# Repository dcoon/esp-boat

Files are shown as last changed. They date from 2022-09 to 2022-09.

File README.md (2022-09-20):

# ESP32 Multitool

ESP32 Multitool is an I/O board for ESP32 microcontroller based projects.  It is designed for IoT projects on a boat but can be used in automotive, RV, and home environments.  It is designed to be inexpensive, robust, energy efficient, and easy to use.  It supports firmware from multiple open source projects including ESPHome, ESPSense, and Platformio.

![[esp32-multitool.png]]

## Features

- 4x Analog Inputs
	- +0-30VDC
	- Measure voltage or resistance
- 4x Digital Inputs
- 4x PWM/Switch Outputs
	- Configurable voltage from VIN, +5V, and External
	- 1A current per channel
- CAN/N2K 
- 1-Wire
- I2C
	- Qwiic and Adafruit compatible I2C connector
- Power
	- +5 - 30VDC Input
	- OVP, RV, and ESD Protection
- Software Compatibility
	- ESPHome
	- ESPSense
	- Platformio

## Examples

TBD

### Tank Level Monitor
### Engine Monitor
### Fan Controller
### LED Dimmer

### More
- Refridgerator Controller
- Barometer & Lightning Detector

## Acknowledgements

### Sailorhat

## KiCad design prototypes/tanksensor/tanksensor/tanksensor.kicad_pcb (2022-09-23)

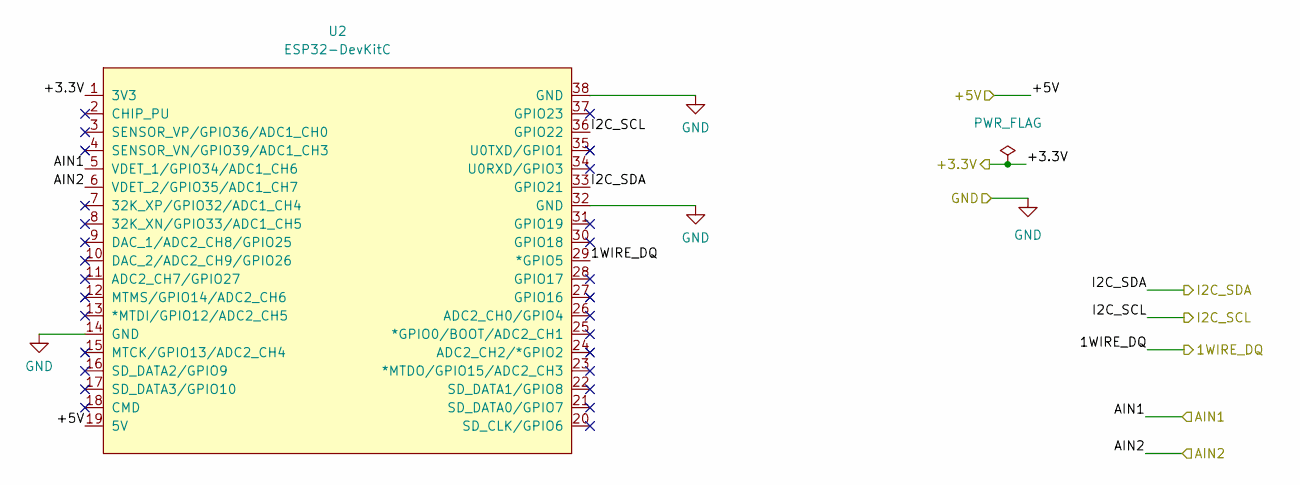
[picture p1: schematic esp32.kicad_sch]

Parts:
U2: ESP32-DevKitC; LCSC n/a

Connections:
+3.3V: U2.1 (3V3); also elsewhere on the board
/1WIRE_DQ: U2.29 (*GPIO5); also elsewhere on the board
/+5V: U2.19 (5V); also elsewhere on the board
/AIN1: U2.5 (VDET_1/GPIO34/ADC1_CH6); also elsewhere on the board
/AIN2: U2.6 (VDET_2/GPIO35/ADC1_CH7); also elsewhere on the board
/I2C_SCL: U2.36 (GPIO22); also elsewhere on the board
/I2C_SDA: U2.33 (GPIO21); also elsewhere on the board
GND: U2.14 (GND), U2.32 (GND), U2.38 (GND); also elsewhere on the board

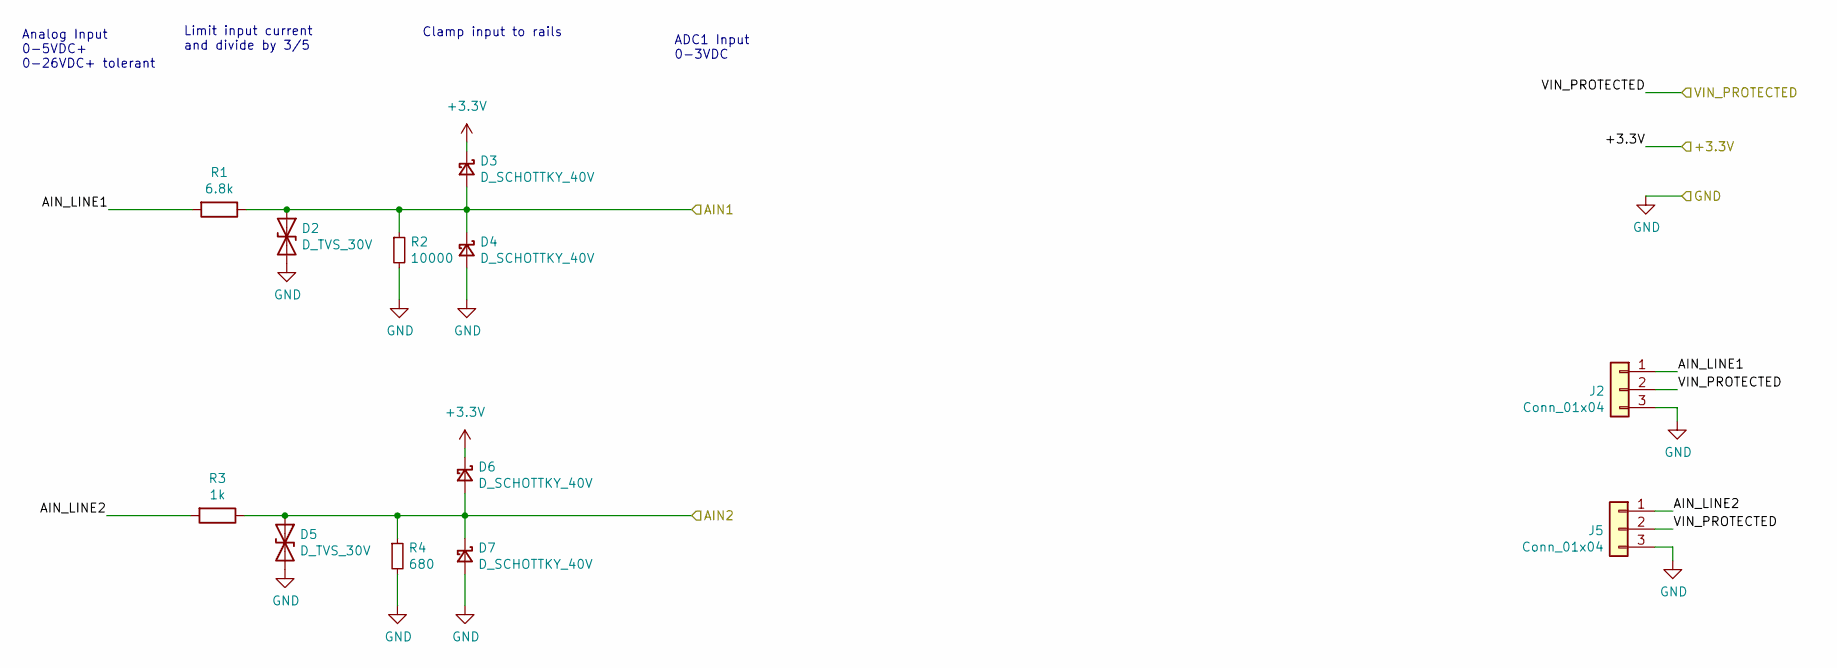
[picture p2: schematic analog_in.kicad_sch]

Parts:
D2, D5: D_TVS_30V; D_SOD-123F; Part SMFJ30CA; LCSC C511921
D3, D4, D6, D7: D_SCHOTTKY_40V; D_SMA; Part B5819W SL; LCSC C8598
J2, J5: Conn_01x04; Molex_KK-254_AE-6410-03A_1x03_P2.54mm_Vertical; Part C145961; LCSC C145961
R1: 6.8k; R_0805_2012Metric; Part 0603WAF1003T5E; LCSC C25803
R2: 10000; R_0805_2012Metric; Part 0603WAF1004T5E; LCSC C22935
R3: 1k; R_0805_2012Metric; Part 0603WAF1003T5E; LCSC C25803
R4: 680; R_0805_2012Metric; Part 0603WAF1004T5E; LCSC C22935

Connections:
+3.3V: D3.1 (K), D6.1 (K); also elsewhere on the board
/AIN1: D2.1 (A1), D3.2 (A), D4.1 (K), R1.1, R2.1; also elsewhere on the board
/AIN2: D5.1 (A1), D6.2 (A), D7.1 (K), R3.1, R4.1; also elsewhere on the board
/VIN_PROTECTED: J2.2, J5.2; also elsewhere on the board
/analog_in/AIN_LINE1: J2.1, R1.2
/analog_in/AIN_LINE2: J5.1, R3.2
GND: D2.2 (A2), D4.2 (A), D5.2 (A2), D7.2 (A), J2.3, J5.3, R2.2, R4.2; also elsewhere on the board

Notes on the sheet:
ADC1 Input 0-3VDC
Limit input current and divide by 3/5
Analog Input 0-5VDC+ 0-26VDC+ tolerant
Clamp input to rails

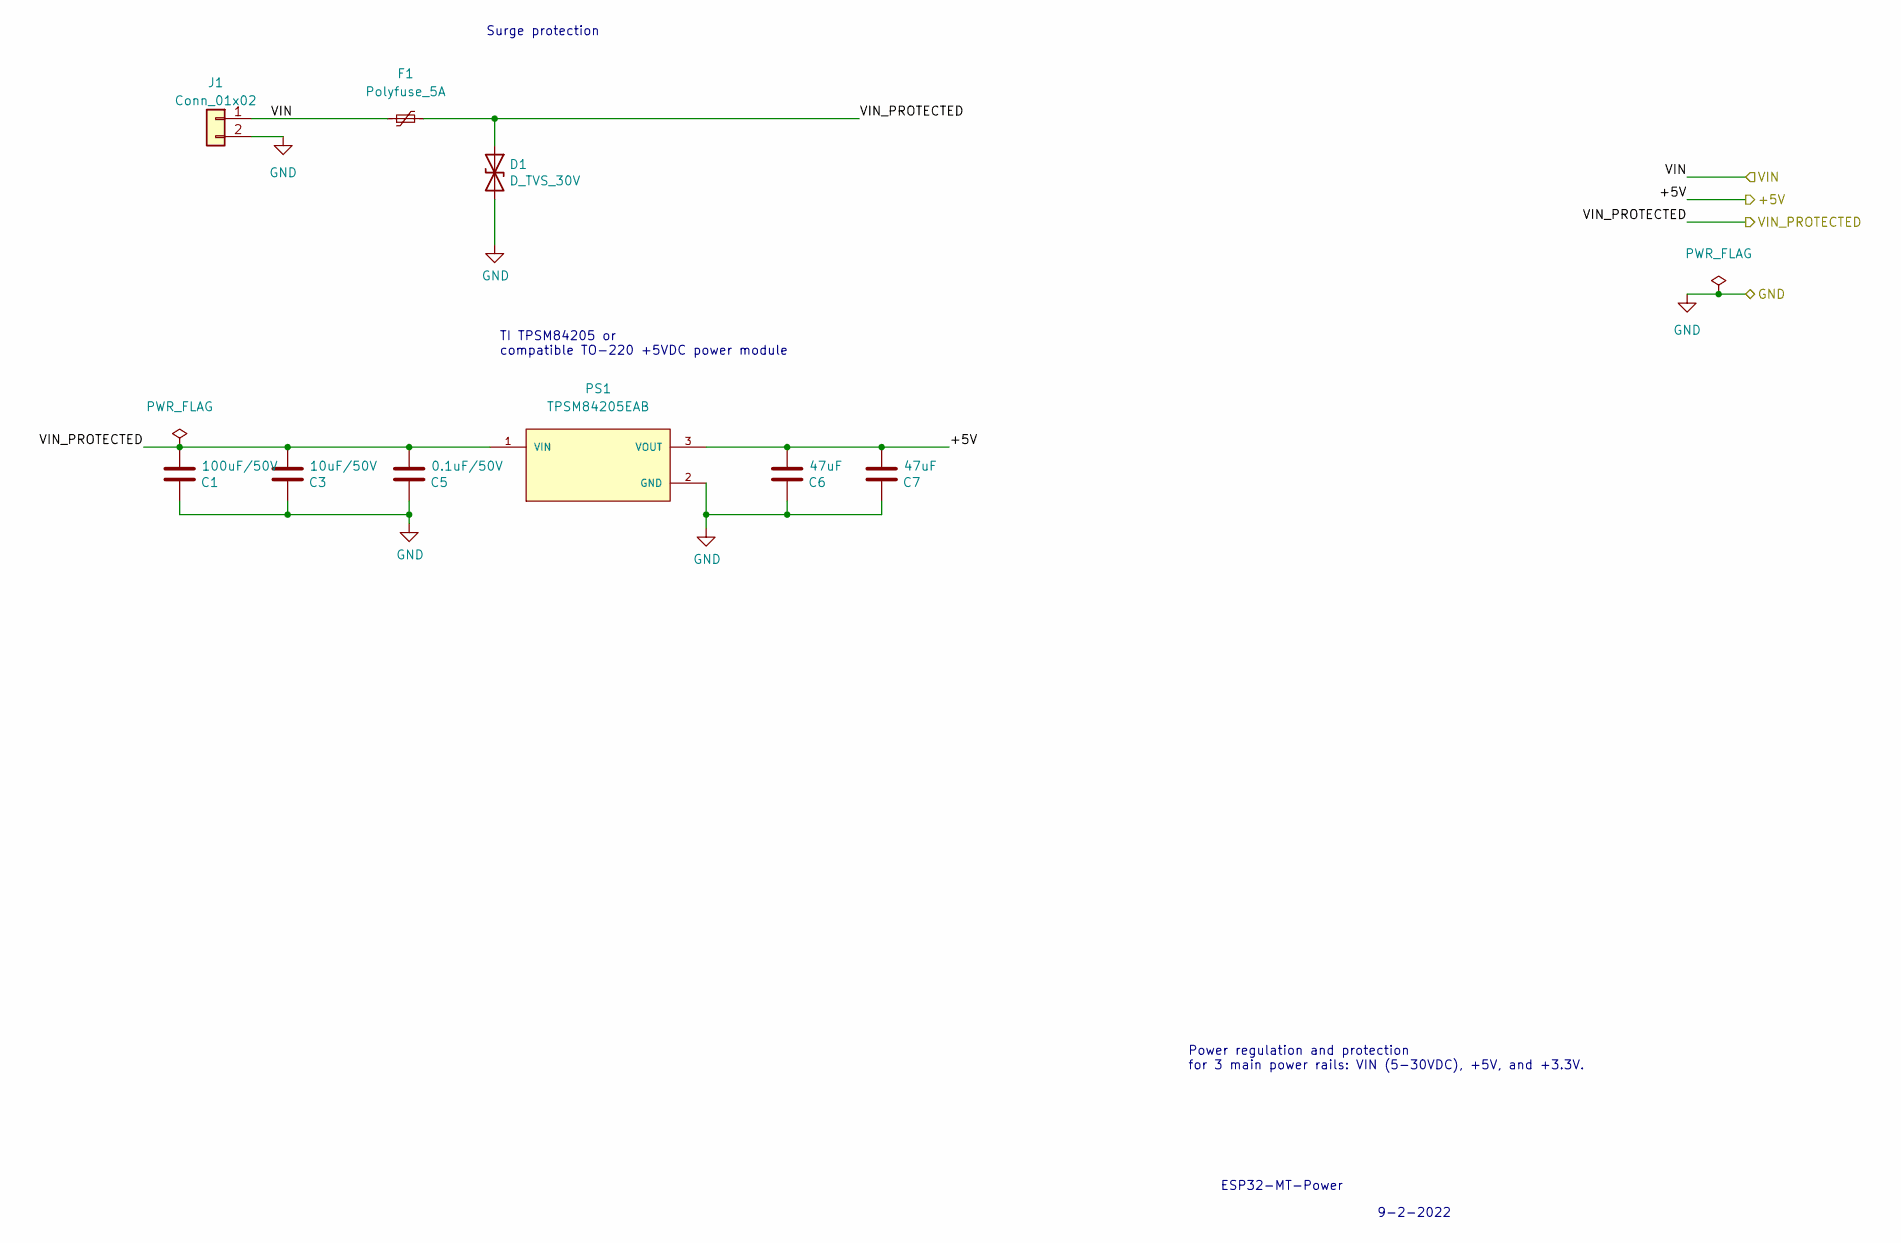
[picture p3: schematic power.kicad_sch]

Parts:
C1: 100uF/50V; C_0805_2012Metric; Part GRM21BR61H106KE43L; LCSC C440198
C3: 10uF/50V; C_0805_2012Metric; Part GRM21BR61H106KE43L; LCSC C440198
C5: 0.1uF/50V; C_0805_2012Metric; Part GRM21BR61H106KE43L; LCSC C440198
C6, C7: 47uF; C_0805_2012Metric; Part GRM21BR61H106KE43L; LCSC C440198
D1: D_TVS_30V; D_SOD-123F; Part SMFJ30CA; LCSC C511921
F1: Polyfuse_5A; Fuse_Bourns_MF-RG1000; Part JK30-200; LCSC C369104
J1: Conn_01x02; Molex_KK-254_AE-6410-02A_1x02_P2.54mm_Vertical; Part VH-2A; LCSC C16728
PS1: TPSM84205EAB; CONV_TPSM84205EAB

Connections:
/+5V: C6.1, C7.1, PS1.3 (VOUT); also elsewhere on the board
/VIN: F1.1, J1.1
/VIN_PROTECTED: C1.1, C3.1, C5.1, D1.1 (A1), F1.2, PS1.1 (VIN); also elsewhere on the board
GND: C1.2, C3.2, C5.2, C6.2, C7.2, D1.2 (A2), J1.2, PS1.2 (GND); also elsewhere on the board

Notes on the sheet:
Power regulation and protection for 3 main power rails: VIN (5-30VDC), +5V, and +3.3V.
9-2-2022
ESP32-MT-Power
TI TPSM84205 or compatible TO-220 +5VDC power module
Surge protection

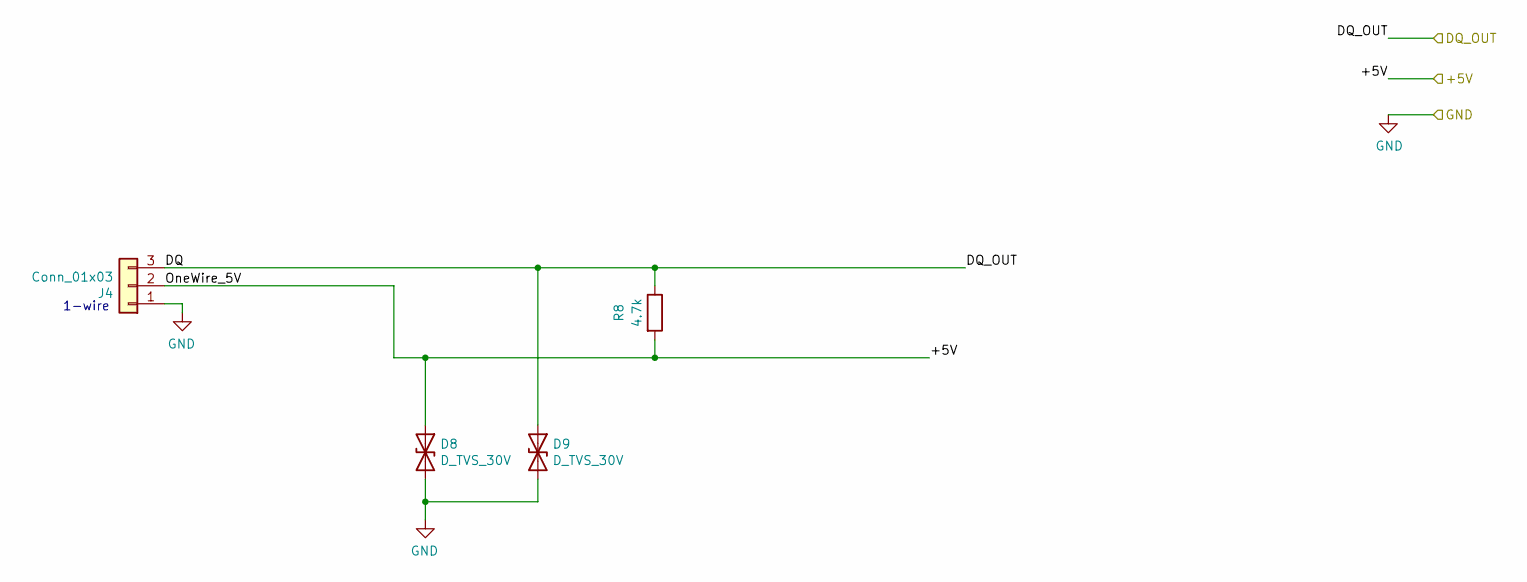
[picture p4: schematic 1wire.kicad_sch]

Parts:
D8, D9: D_TVS_30V; D_SOD-123F; Part SMFJ30CA; LCSC C511921
J4: Conn_01x03; Molex_KK-254_AE-6410-03A_1x03_P2.54mm_Vertical; Part C145960; LCSC C145960
R8: 4.7k; R_0805_2012Metric; Part 0603WAF4701T5E; LCSC C23162

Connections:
/1WIRE_DQ: D9.1 (A1), J4.3, R8.1; also elsewhere on the board
/+5V: D8.1 (A1), J4.2, R8.2; also elsewhere on the board
GND: D8.2 (A2), D9.2 (A2), J4.1; also elsewhere on the board

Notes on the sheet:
1-wire

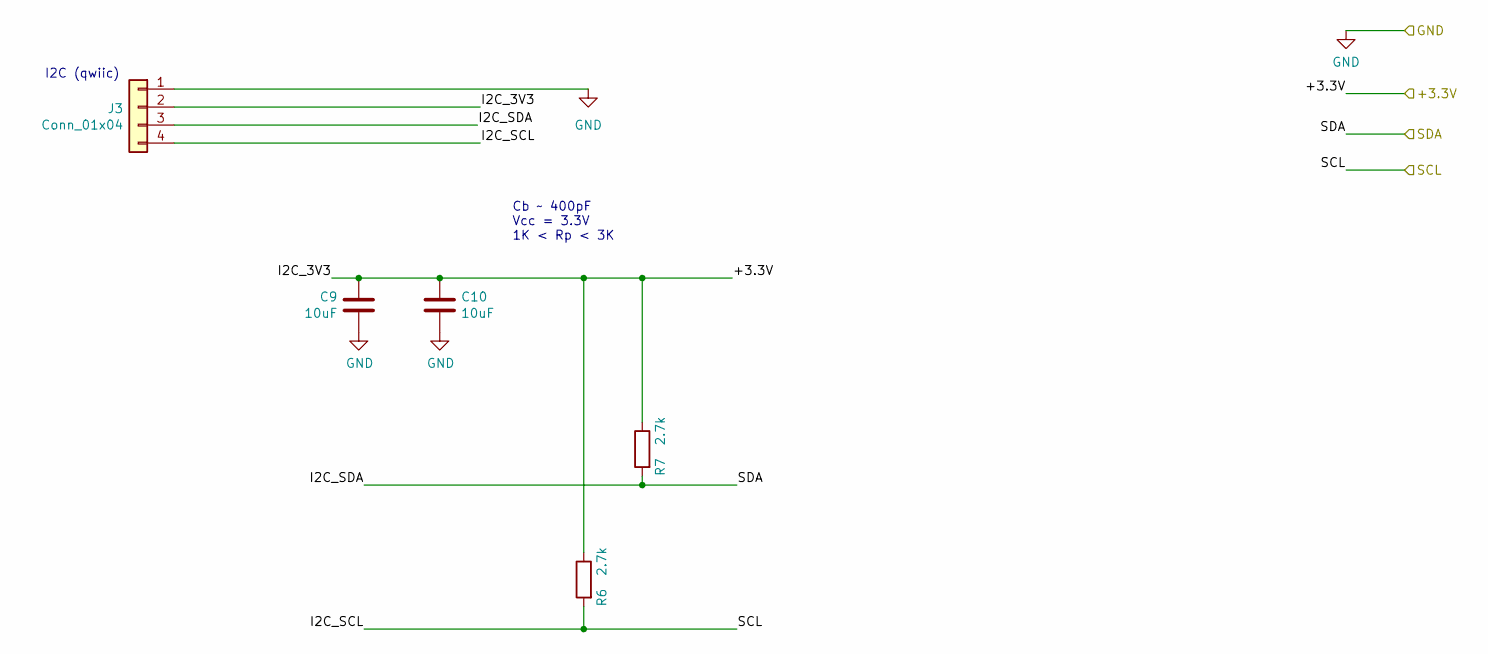
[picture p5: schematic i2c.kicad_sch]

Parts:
C9, C10: 10uF; C_0805_2012Metric; Part CL10A106KP8NNNC; LCSC C19702
J3: Conn_01x04; Molex_KK-254_AE-6410-04A_1x04_P2.54mm_Vertical; Part C145961; LCSC C145961
R6, R7: 2.7k; R_0805_2012Metric; Part 0603WAF2701T5E; LCSC C13167

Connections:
+3.3V: C9.1, C10.1, J3.2, R6.1, R7.1; also elsewhere on the board
/I2C_SCL: J3.4, R6.2; also elsewhere on the board
/I2C_SDA: J3.3, R7.2; also elsewhere on the board
GND: C9.2, C10.2, J3.1; also elsewhere on the board

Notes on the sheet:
Cb ~ 400pF Vcc = 3.3V 1K < Rp < 3K
I2C (qwiic)

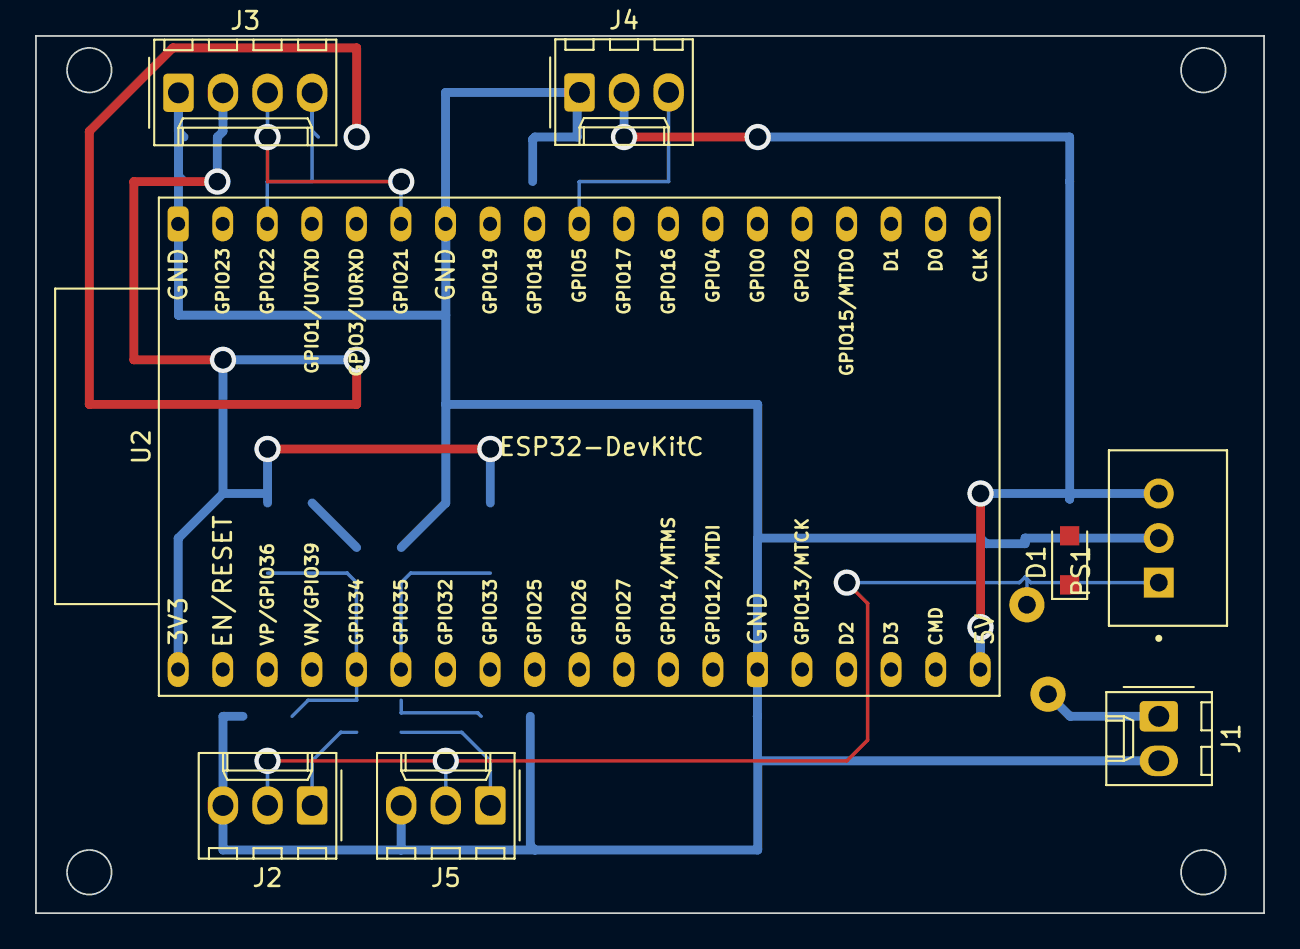
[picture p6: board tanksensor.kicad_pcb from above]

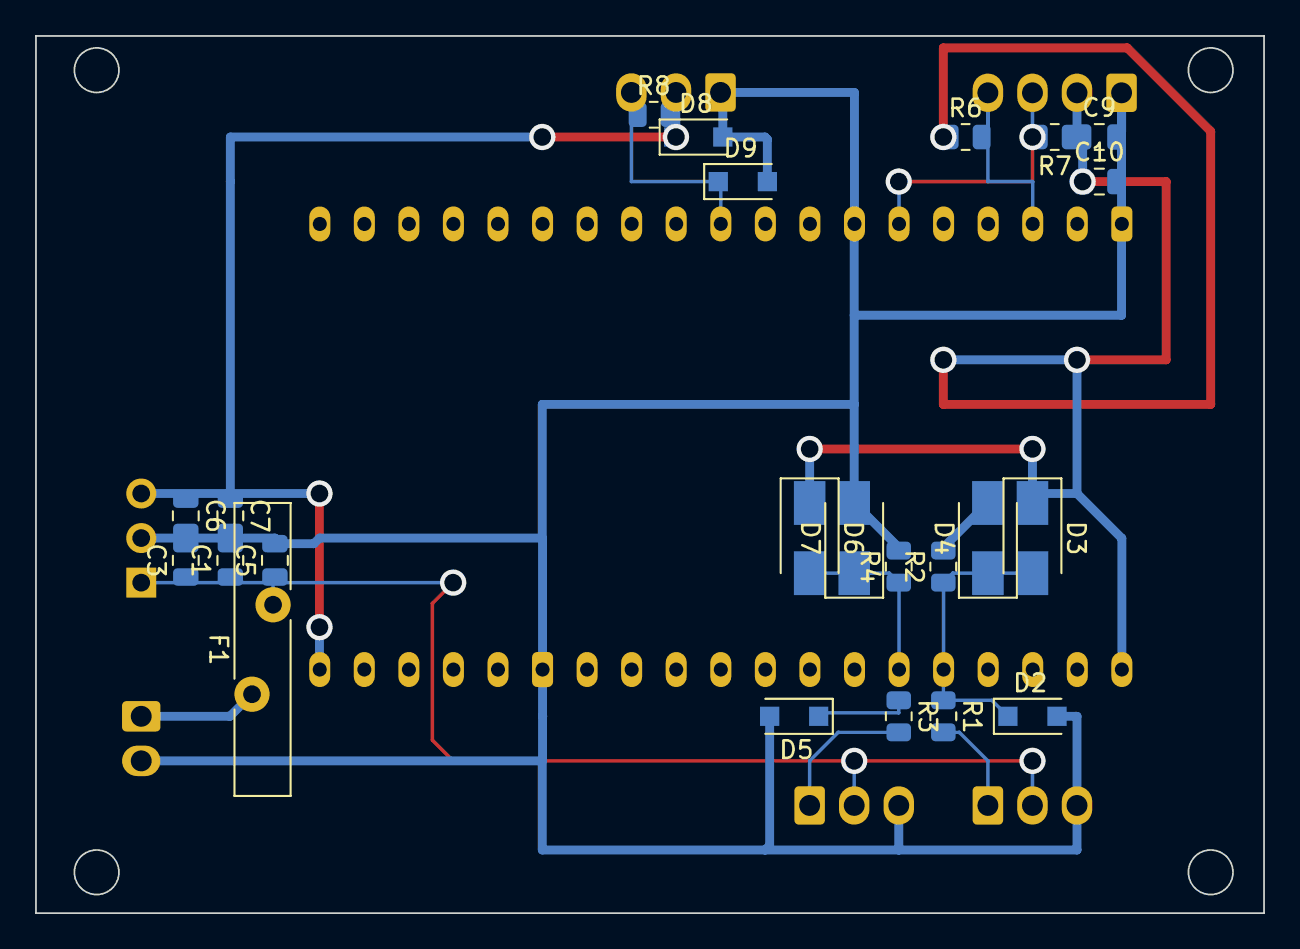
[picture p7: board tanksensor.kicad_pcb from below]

Board: 2 copper layers, 70.0 x 50.0 mm, 31 parts (23 on the bottom side), 12 nets.

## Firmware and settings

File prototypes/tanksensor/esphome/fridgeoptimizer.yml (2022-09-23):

esphome:
  name: starboard-freezer

esp32:
  board: esp32dev
  framework:
    type: arduino

# Enable logging
logger:

# Enable Home Assistant API
api:
  password: ""

ota:
  password: ""

wifi:
  ssid: "svHarmony24"
  password: "I Love Harmony!"

  # Enable fallback hotspot (captive portal) in case wifi connection fails
  ap:
    ssid: "Staboard-Freezer"
    password: "CpIzIQ7pnW3Q"

captive_portal:

switch:
  - platform: gpio
    id: "starboard_freezer_compressor"
    name: "Starboard Freezer Compressor"
    pin: 16
    restore_mode: always_off

dallas:
  - pin: 23
    update_interval: 5s

i2c:
  - sda: 21
    scl: 22

sensor:
  - platform: dallas
    address: 0xa8012052cbcfa828
    id: "starboard_freezer_temperature"
    name: "Starboard Freezer Temperature"
  - platform: ina3221
    address: 0x42
    update_interval: 5s
    channel_3:
      shunt_resistance: 0.025 ohm
      current:
        name: "Starboard Freezer Current"
      power:
        name: "Starboard Freezer Power"
      bus_voltage:
        name: "Staboard Freezer Voltage"
climate:
  - platform: thermostat
    name: "Starboard Freezer Thermostat"
    sensor: starboard_freezer_temperature
    default_target_temperature_high: 4C
    visual:
      min_temperature: -10C
      max_temperature: 20C
    min_cooling_off_time: 180s
    min_cooling_run_time: 180s
    min_idle_time: 30s
    cool_action:
      - switch.turn_on: starboard_freezer_compressor
    idle_action:
      - switch.turn_off: starboard_freezer_compressor
    startup_delay: true
    cool_deadband: 3C
    cool_overrun: 3C

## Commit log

2022-09-20 First pass at tank sensor proto
    [1wire.kicad_sch, analog_in.kicad_sch, esp32.kicad_sch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]
2022-09-23 Rev of the tanksensor pcb and esphome config
    [1wire.kicad_sch, analog_in.kicad_sch, i2c.kicad_sch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]
